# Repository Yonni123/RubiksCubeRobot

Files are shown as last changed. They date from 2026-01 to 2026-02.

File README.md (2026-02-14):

# Rubik's Cube Robot
<p align="center">
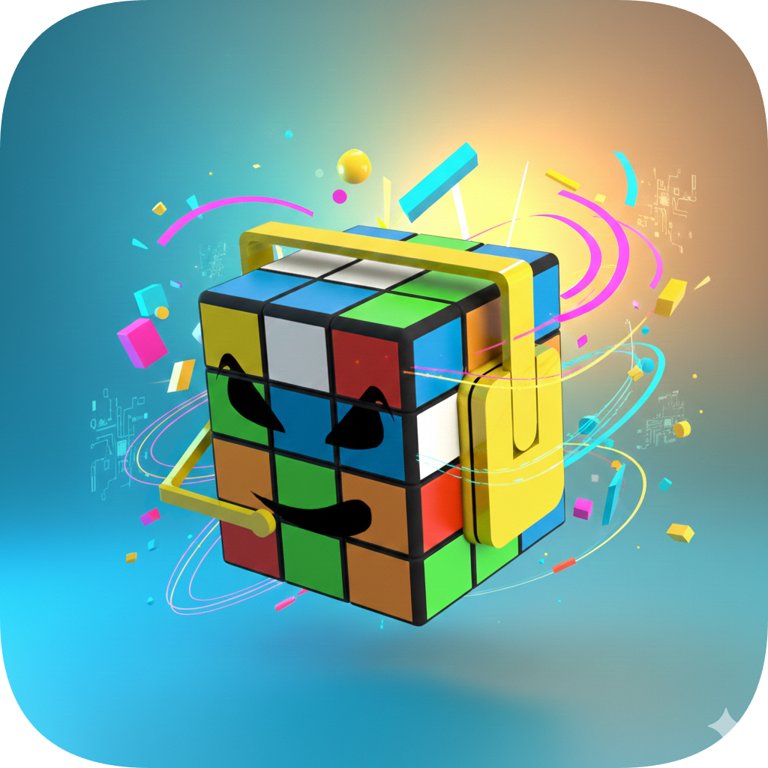
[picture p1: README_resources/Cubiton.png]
Pi-hole website
  
  <br>
</p>

An autonomous robotic system that can visually scan a scrambled Rubik's cube, compute the optimal solution, and solve it through precise servo-controlled manipulation.

## Video demo
<p align="center">
  <a href="https://www.youtube.com/watch?v=RQn-u8popRQ">
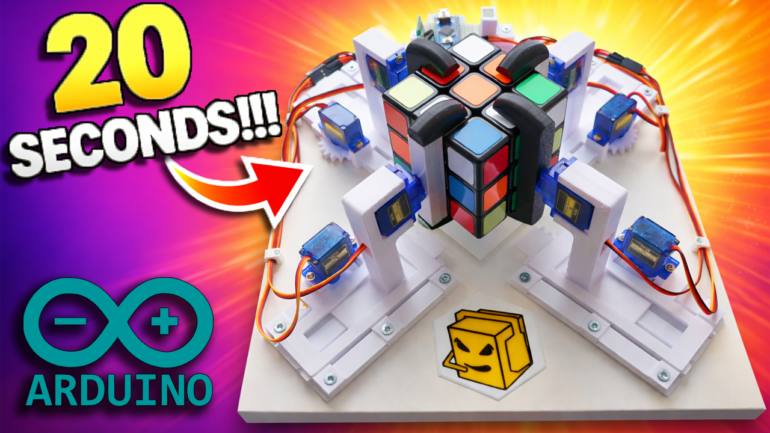
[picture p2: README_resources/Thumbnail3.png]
Project Demo Video
    
  </a>
</p>

## Project Overview

This project combines:
- **Hardware**: Arduino-controlled robotic actuators with 8 servo motors
- **Software**: Android mobile app for camera-based cube detection and Bluetooth control
- **Algorithms**: Kociemba two-phase algorithm for optimal cube solving

The system uses computer vision to analyze all 6 faces of a Rubik's cube, calculates the minimal solving sequence, and then executes it robotically.

## Getting started
Each folder in this repo is responsible for a different thing, with its own README.md that explains it further. I recommend doing them in the following order:
### Hardware
This is where you'll find hardware things that you will need, along with STL files ready for 3D printing and instructions for which parts to 3D print and how to assemble them. You'll also find Fusion 360 files of the same STL files in case you want to tweak them yourself. At the end, you should have the robot ready to be programmed.

### Arduino
When you've built the robot, it is time to flash the arduino with the firmware and configure it. This directory has a README that will show how this is done, and explain the API interface of the robot and how to talk with it.

### Cube Solver
Since the entire robot with the arduino is just sitting and waiting for commands, this Cube Solver is an android app that I developed as an example for how to control the robot. It combines computer vision with the phone's camera to scan the cube with Kociemba's algorithm to find the optimal solution for the cube, and streams the solution to the robot, which executes it. The README there shows how to install the app on an android phone and use it, but not much about the code itself, if you wanna improve it, be my guest :)

## Workflow: Solving a Cube

1. **User starts app** → Connects to Arduino via Bluetooth (HC-06)
2. **Scan Phase**:
   - Opens Scan tab
   - Robot rotates to expose each face
   - User taps "Scan Face" for each of 6 faces
   - App captures and processes images
3. **Processing**:
   - Converts color detection to Kociemba format
   - Sends to two-phase solver (embedded `.jar`)
   - Returns optimal move sequence
4. **Solving**:
   - User sets speed
   - Taps "Solve"
   - App sends `MOVE` command with sequence
   - Arduino executes servo movements
   - Phone listens for IDLE/BUSY status updates
5. **Done**: Cube is solved, robot returns to rest position

## Known issues
The layout of the android application is different from device to device. Depending on resolution, it might be perfect or completely ruined and almost unusable.

## Future Improvements

- Make the scanning computer vision part better
- The SEQ command and the API in general takes up the entire RAM cuz I was lazy
- Actually implement the control tab
- When pressing Solve, Open or Close buttons, disable them immediately and wait for robot to respond (just like we do with scan buttons)

---

**Created**: January 2026  
**Author**: Yonan Yonan  
**License**: Do whatever the fuck you want license, as long as you don't sell any of this or profit from it in any way

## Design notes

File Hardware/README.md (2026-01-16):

# Hardware
In this folder, you'll find STL files, Fusion 360 files, electronics and much more..

## What you'll need (aside from 3D printing)
A wooden base. Minimum dimensions of 240x240mm. But, in my case, I needed it a little longer for my breadboard, so I had 240x270mm. Make sure the width is 240mm and the length is at least 240mm, but it can be as long as you need. The depth should ideally be between 20-30mm since we will be screwing and nailing things on this base. But my point is, the actuators themselves will take up space of 240x240mm in total.

Eight servo motors (SG90 or its metal equivalent that has the same dimensions). 

A breadboard with some jumper wires for circuitry.

Power adapter that is a steady 5 volts and at least 3 amps. Anything less will not work, but ideally, I would recommend more amps.

An arduino, any arduino here will work, but I went with Arduino Nano since it is small and fits nicely on the breadboard.

A breadboard or a PCB, whatever you want to connect the wires and circuitry really..

HC-06 or HC-05 bluetooth module for communication between the phone and the robot.. oh, and, an android phone.

3mm wooden screws that are 15mm long (to screw things into the wooden frame) and extra small screws (the same type that comes with the servo).

## Screw holes
I have made something I called "drill_jig.stl" cuz idk what else to call it. Anyway, it is a part that you can 3D print that will help you with drilling the screw holes in the right place. You just grab your 240x240mm wooden base (or draw a square of that size on it) and line it up with each of the 4 corners, and it will show you where the holes should be. You can mark them, drill and then throw that part away. You can also create a 2D version of it if you want and print it on paper.

## 3D printing, STL and Fusion 360
Let's look at how the final robot should look like:

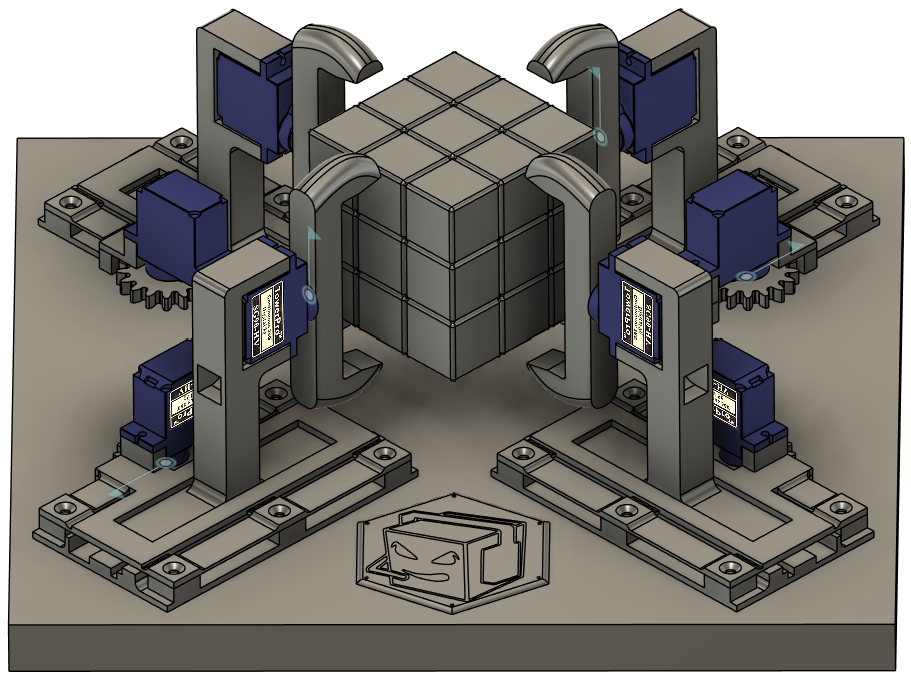
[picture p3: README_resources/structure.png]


To see a 3D version of that image, with clear parts, access this link: https://a360.co/49qhMGL

The password is: Cubiton

I do strongly suggest looking at it and using it as a manual for assembling the parts.

We can see four actuators. Two of them are normal and two of them are mirrored. (the definition of mirrored and normal is just my own). The upper-right in the image above and the bottom left actuators is what I defined as normal. The other two is what I defined as mirrored. Depending on where you want the gear and the servo to end up, you might want either all mirrored, all normal or like I did, two mirrored and two normal. If you want 3 mirroed or 3 normals you aren't normal :)

### Actuators
Each actuator is built up of 5 parts (aside from the two servos):
1. Grabber - the claw that grabs the rubiks cube. Mirroring doesn't matter for this one.
2. Slider - This is what holds the grabber and its servo, its the part that slides back and fourth.
3. Channel top - The part that holds the slider in the channel that it slides on. 
4. Channel bot - The channel itself that the slider should slide across. Since it can be rotated 180 degrees, mirroring shoudn't matter for this too.
5. Gear - This is what is mounted onto the bottom servo, that grabs the slider and pushes it back and fourth, also no mirroring. 

I hope this image makes the parts more clear:

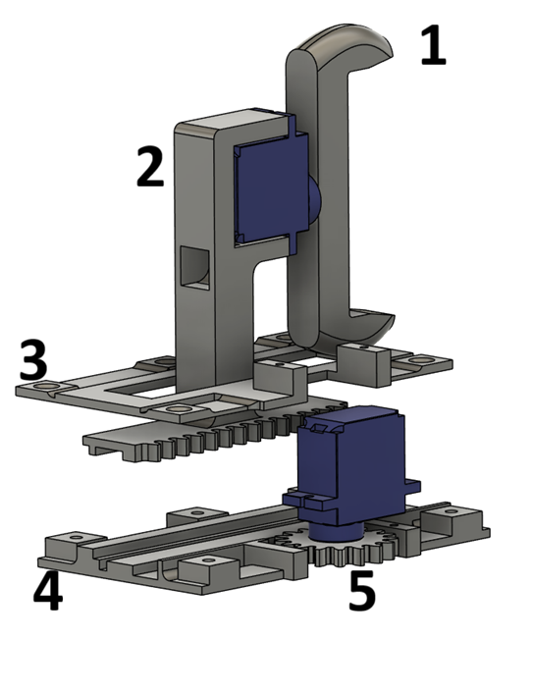
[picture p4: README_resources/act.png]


All of these parts make up one actuator, and we want four of them. First decide mirroring and what direction you want the gear servo to face. From now on, I will go on making two normals and two mirrored actuators.

#### Grabber
I have designed two types of grabbers, you can choose any one you like. One of them has a perfect fit in my servos, it might not fit your servo. The other grabber has a cut-out where a servo arm can be mounted onto it (the thing that comes with your servo). 
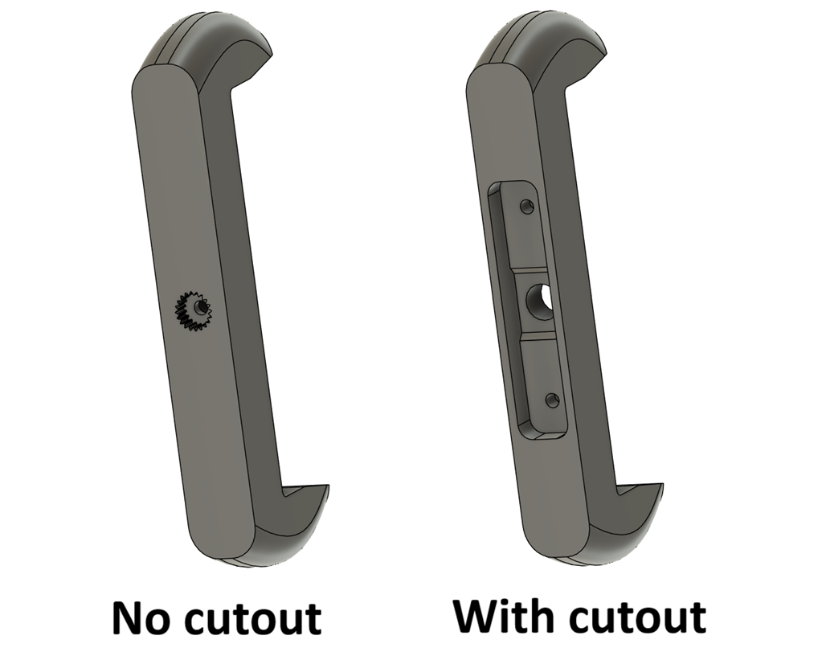
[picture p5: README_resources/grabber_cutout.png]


#### Gear
The gear has small cutout too, I don't recommend having a snap-on without anything holding it in place as this will move the entire slider back and fourth. What I did is have the servo arm with two little umm.. things? at the side.. I just snap off the long arms and only use the short arms because the gear is smaller. I hope this image will make it make sense :D
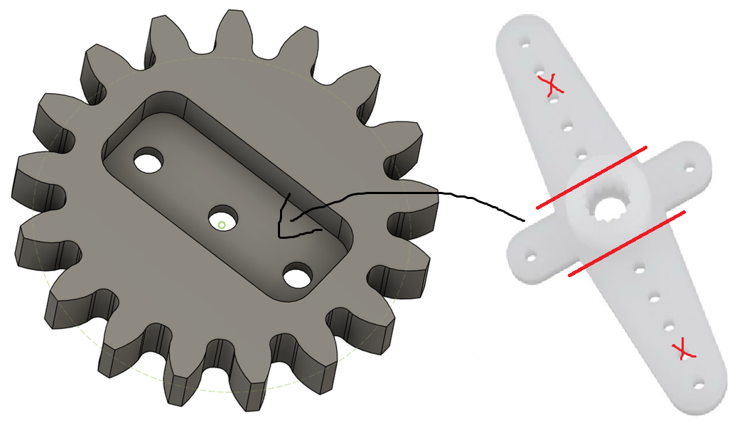
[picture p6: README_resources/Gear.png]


#### 3D printing
Before 3D printing anything, keep in mind that all the hole sizes and dimensions and cutouts fit my servos and my setup. Make sure:
- The cutout for the servo arms (or the grabber without the cutout) actually fits your servos and servo arms
- The grabber itself is a little bigger than the side of your cube (there must be a small 3-5mm gap between them, the cube should never get stuck inside the grabber)
- The screw holes themselves om the channel top and bottom, these will be screwed onto the wooden base
- The slider and the channel bottom, have a tolerance of 0.15mm, depending on your printer, you might wanna check that too otherwise it will not smoothly slide

I will make the Fusion 360 (where I designed them) files of these parts available in the Fusion 360 folder in this directory, you should be able to load them into Fusion and tweak them if you need to.

This is how I recommend you 3D print all parts (showing a single, normal actuator, the mirrored version should be printed in the exact same way)
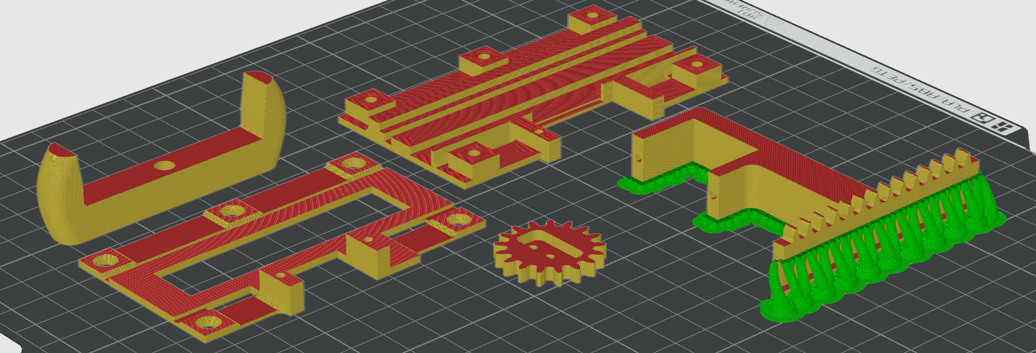
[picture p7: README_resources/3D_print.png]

The key takeaway is that, the gears on the slider needs to point up, only support the entire bottom face, and the two things that stick out at the bottom that will go into the channel later. Make it a manual tree support in Bambu Slicer. Also, make the channel bot (part numebr 4) has a top surface pattern set to concentric, so that the layer lines go along the channel, making the slider slide onto it smoothly.

When you have 3D printed these parts, you put them together like this:
But the bottom channel(4) on the wooden base. Put the slider(2) on it and make sure they slide smoothly (not too stiff or too wobbly). Put the top channel part(3) on top of them and screw them together onto the wooden base (5 screws in total).

Now, you can grab two servos, mount the gear on one servo and the grabber on the other (make sure the grabber is mounted in a way that lets it go between fully left, middle, and fully right). Slide the slider all the way in, rotate the gear manually so that it is also all the way in and mesh them together (to make sure the limit of the servo is literally the limit of how much you can push in the slider). Then just screw it in place. You should be able to slide the slider using the servo now, all the way in and however far back it goes (it goes back way too far we won't use all of it). Screw the grabber servo in place too and now you should have one actuator done. Repeat this 4 times.

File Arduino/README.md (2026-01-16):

# Arduino
Here you will first find how to wire things up in the arduino, and how to calibrate your servos with documentation of the overall arduino code and how it works. This is the slave part with the API that sits there and waits for commands.

## Circuit
You need an HC-06 or HC-05 bluetooth module for communication. When wiring up the servos, the PWM pin (orange wire usually) does not matter as long as you connected to one of the D2-D15 pins on the arduino (D0 and D1 are RX and TX, avoid those!). The TX and RX pins should be hooked up to the arduino's TX and RX using a voltage divider (since HC-06 logic works with 3.3v and not 5v). Below diagram shows how to wire up the HC-06 with a single servo (do the same with with the otehr 7 servos and just connect them to any diginal GPIO pins, it doens't matter which goes where.). The below diagram also assumes the power adapter provides a steady 5v with 3 amps or above. You can add capacitors to the motors too but I didn't bother.
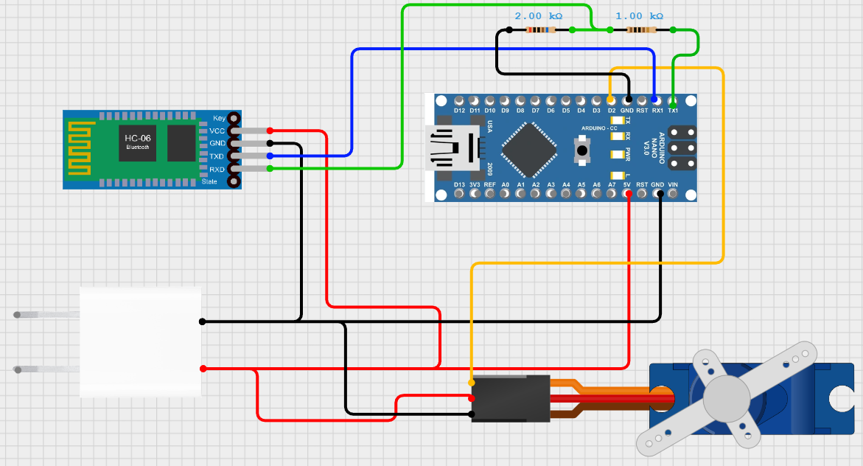
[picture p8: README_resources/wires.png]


### Actuator Definition
Which pin you connected each servo to does not matter, but the code expects this exact actuator definition (assuming the front of the robot is where my logo is):  
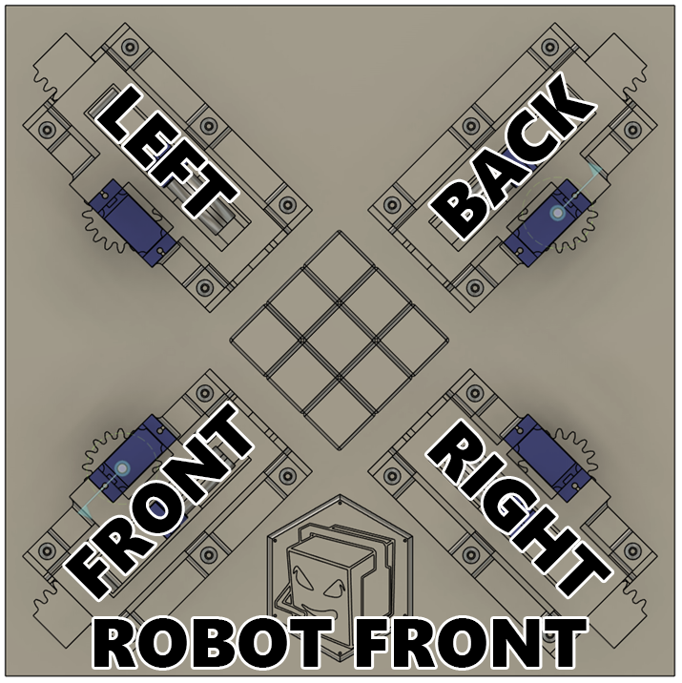
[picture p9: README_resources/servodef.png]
  
Each actuator will have a slider servo and a spinner servo. The slider is what makes it slide back and fourth, it is the servo with the gear. The spinner is the servo with the grabber that grabs the side of the rubiks cube and spins it. The pins you connected must be configured later based on this exact definition.

### Servo States
This application has a single servo class, with the exact same states, but they mean different things for spinners and sliders.

#### Spinner servo
Each spinner servo can move to 5 distinct positions:
- **STATE_C**: Center (fully centered)
- **STATE_L**: Left (fully left)
- **STATE_R**: Right (fully right)
- **STATE_l**: Center-left (45° between C and L)
- **STATE_r**: Center-right (45° between C and R)

#### Slider servo
- **STATE_C**: Center (Barely touching the rubik's cube without stalling)
- **STATE_L**: Left (Fully pressing into the rubik's cube, stalling)
- **STATE_R**: Right (Release, slide out, in this state, spinner can move freely and won't touch the cube)  
I guess sliders have a STATE_l and STATE_r as well since they use the same servo class, but here they do not make sense :) they just exist...

## Configuration (`Config.h`)
Before flashing your arduino with any of my code, I recommend using the servo sweep example code that comes with the arduino IDE to test all your sliders and spinners, to make sure all the wiring is correct. Then, open [Config.h](Config.h). In this file, you will find the definition for all the servo pins. You should change these to whatever digital pins you connected your servos to, depending on the actuator definition we talked about earlier. The other configuration is in case you want to run the program in calibration mode instead of normal mode (we will talk about it soon) and two buffers. One for SEQ command, which let's you control each servo individually, and MOVE command which let's you tell the robot actual rubik's cube moves. These buffer sizes worked for me so I do not recommend changing them unless you have a reason to. We will talk about these commands later.

## Calibration
> ### SERVO LIBRARY ISSUE
> **NOTE:** Before calibrating your servos, please be aware that my servo class is an abstraction on top of the standard `Servo.h` Arduino library. 
>
> **THE ISSUE:** You may find your servos have a "hard-limit" where they stop at 45° and 135° and refuse to go further. This is a known overflow bug within the official Servo library itself.
>
> **THE FIX:** You must manually patch the library. I found a community fix that resolves this overflow issue:
> * **Fix Link:** [GitHub Commit 7b4f264](https://github.com/arduino-libraries/Servo/pull/101/commits/7b4f26462c5053ac967b237c602000ad9ba54200)
>
>I highly recommend applying this change in your local library files; otherwise, it may be impossible to calibrate the servos correctly.  

Each servo is different, and STATE_C can mean different things for different servos. So, we must calibrate them once everything is working. Set the CALIBRATE flag to true in [Config.h](Config.h). However, try not to stay in this mode for too long as it keeps the servos constantly powered. Even if they aren't stalling, they are constantly micro-adjusting and will overheat if you leave it in this mode for a long time. This is mainly because I was too lazy, but meh, it needs to be done just a single time. After you set the CALIBRATE flag, remove the HC-06 bluetooth module and flash the arduino. Once it's done, open a serial monitor (BAUD 9600) and type H. It should show this message:
```
Servo calibration tool commands:
0-7 : select servo
c   : set state CENTER to calibrate center
l   : set state LEFT to calibrate left
r   : set state RIGHT to calibrate right
+/- : increase/decrease step size
*// : increase/decrease step size * 10
</> : increase/decrease center deviation (spinners only)
p   : Print current calibration values
w   : Write calibration to EEPROM
```  
First, select a servo to calibrate by writing a number between 0-7 in the serial monitor, it will show what you selected and current pulse and state after you press enter. After that, select state by sending r, l or c. (STATE_r and STATE_l cannot be selected here because their pulse will be calculated as the pulse between your STATE_R and STATE_C pulse). The idea here is that each state should be associated with a pulse for each servo. I recommend putting all sliders in C state, make them hold the cube in the middle, then put them in state R and clibrate it so that they are just out of reach of the cube, then state L that makes them press into the cube (to hold it up).  
Then, move onto the spinners, make sure the R and L are not a fully horizontal grabber, but a grabber that spins a little further than that. Because the grabber is a little bit bigger than the cube, to compenstate for that gap, it needs to spin a little more than 180 deg and a little less than 0 deg. The cheapest servos I bought was able to do it with enough calibration so there shouldn't be a problem :)  
However, going back to the center is a nightmare because it also needs that compensation. If the grabber only goes to the center, the side of the cube won't be fully at the center otherwise. So, I added something called center deviation (might be a wrong name, this is compensasion) that makes the grabber go a little bit to the left off the center, if it's coming from the right, and vice versa. But if it's in the center and it gets another center command, then it will not add compensasion. So, for true center, just send the center command twice.
When all these calibrations are done, you can press P to print them, or W to write them to the EEPROM so when you run it in normal mode, they will be read from there.

## **API Layer** (`API.cpp/h`)

Turn off the CALIBRATE flag and flash the arduino again (still without HC-06). In the serial monitor from the arduino IDE, you can type H again and this help message will be printed:
```
Commands:
HELP
PING
STATUS [servo]
SEQ <string>|C
MOVE <delay_ms> <orientation> <moves>
```
- `PING` - Connection test (should respond with PONG)  

Before explaining the rest of these commands, we should explain how we refer to each servo and state and cube orientation.
- Servo:   
   `R`, `L`, `F` or `B`: refers to RIGHT, LEFT, FRONT or BACK Slider servo  
   `r`, `l`, `f` or `b`: refers to RIGHT, LEFT, FRONT or BACK Spinner servo  
- State:  
   `R`, `r`, `C`, `l`, `L`: STATE_R, STATE_r, STATE_C, STATE_l, STATE_L  
   These work the exact same for spinners and sliders, but don't use r and l for sliders, again, they do not make sense  
Because of the mechanics of this robot, it can not access the UP and DOWN faces of the cube directly. It must flip the entire cube around.
When the cube is flipped, the UP and DOWN faces become the RIGHT and LEFT faces in the robot. The Right and Left faces on the cube are now pointing up and down and are inaccessible directly. In this orientation after the robot is flipped, the orientation is `INVERT` and the orientation is `1`. When the cube is NOT flipped and the UP and DOWN cube faces are inaccessible, it is `NORMAL` and orientation is `0`  

### STATUS command
- `STATUS [servo]` - Query robot state (IDLE/BUSY) or individual servo state (R, C or L)

### SEQ commnad
- `SEQ <string>|C` - Execute a predefined servo sequence or cancel.
If you just send `SEQ C`. It will cancel ANY operation it is currently doing and disable all servos. This is good for some kind of ABORT button. If it's already IDLE it will not do anything.  
If you send a sequence string instead, it is built like this:
`"<SERVO><STATE><SERVO><STATE>[OPTIONAL DELAY]"` and so on...
The sequence string will be executed from left to right IMMEDIATELY at the same time! unless it encounters a delay in the string, in which case it will wait and that amount of milliseconds before continuing the rest.
Example:
```
SEQ rRBL250fr  → Move right spinner to R, back slider to L, at the same time!, wait 250ms, front spinner to R
```  
You should plan your delay so that spinners aren't hitting each other, servos have enough time to move into position, but making the delays too large will cause the sequence to slow down, which is not ideal. You should just experiment with it. The perfect servo calibration can have delays as low as 120ms! but start with 250ms.

### MOVE command
- `MOVE <delay> <orientation> <moves>` - Execute standard Rubik's notation moves (U, D, L, R, F, B)
While you can use SEQ command to manually execute moves, it is exhausting to think in terms of SEQ instead of MOVES. It is also not possible as it stores the entire sequence stirng in RAM. A single move involve at least 4 servos, 6 if a cube flip is needed (U and B moves). A simple solution string will quickly blow up to a SEQ command over 2kb! This is why you should use the MOVE command to execute moves intead!  
You tell it how long it should wait for servos to get into position after commanding them, the start orientation of cube (how it is oriented right now, this is 0 for most of the time but set it to 1 when you need to) and following by the moves string defined as:  
R, L, F, B, U, D -> clockwise cube rotation of that face.  
r, l, f, b, u, d -> counter-clockwise cube rotation of that face.  
I know the standard move string is "FBF'U2" bla bla bla... but I wanted a simpler version where each character in the string mean a move! the equivalent of the move string I just said in my definition will be "FBfUU".  
Example:
```
MOVE 210 0 UfRF  
→ Cube orientation is NORMAL now (0), execute UP clockwise, so flip cube, then turn the face 90 degrees clockwise. 
→ Turn the FRONT face counter-clockwise
→ Turm the RIGHT face clockwise, but the orientation is INVERT now, we flipped it before, so flip it back and turn RIGHT face clockwise
→ Turn FRONT clockwise
```

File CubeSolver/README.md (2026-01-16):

# Cube Solver

This is the Android application component of the Rubik's Cube Robot project. It provides a mobile interface for scanning a scrambled Rubik's cube using the device's camera, computing the optimal solving sequence with Kociemba's two-phase algorithm, and sending the solution to the Arduino-controlled robot for execution.

## Disclaimer
I must say that 90% of this app is fully vibe-coded and AI generated. I focused fully on designing the robot mechanics, 3D printing, CAD and the Arduino C++ code. I did NOT want to focus on learning Kotlin or Android Studio with its Compose UI. For these reasons, I let the AI generate most of that code, which breaks every best-practices you can think of. I simply did not care as long as it was working, but this app is an example of how you should NOT use AI in your work :)  But, in this README, I will explain how to use the app rather than how the code works.

## Installation
There should be an APK file somewhere in the Release of this github repo, just install it on any android device that has a camera and Bluetooth.

## Usage

1. **Setup**:
   - Ensure the Arduino robot is powered on and Bluetooth module is active
   - Before launching the app, open bluetooth tab and connect to the robot from there. It should be paired

2. **Bluetooth Connection**:
   - Launch the app and press Connect button at the top, it will show you a list of paired devices, choose the robot

3. **Scanning the Cube**:
   - After connection, go to SCAN tab, and press start scanning.
   - The robot will show you each side it wants to see, and you should scan it from the front of the robot.
   - After scanning all 6 sides, it will go to the confirmation phase, make sure all colors are correctly detected
   - The confirmation phase is important since the AI did not do a good job at color detection from images and I'm too lazy to fix it

4. **Solving**:
   - When scanning is done, you can go back to Home tab and you should see a Cube State along with a Solution
   - If your calibrations were perfect, you should be able to set the speed to 100% and press solve (I was able to)
   - Robot should just execute moves the solution :) If anything goes wrong press the ABORT button.

## Troubleshooting
If you need to troubleshoot anything, don't do it in the android app as it can not do much. Remove the HC-06 module, connect the arduino to your computer and give it SEQ and MOVE commands from the Arduino IDE Serial Monitor.

## Development
For code improvements or modifications, refer to the source code in `app/src/main/`.

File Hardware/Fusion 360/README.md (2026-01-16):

Open Fusion 360. File -> open and choose Main+assembly.f3z
There is also a .stp file in case you want to open these in another CAD software.
It will import ALL parts and main assembly and you can play around with them however you want

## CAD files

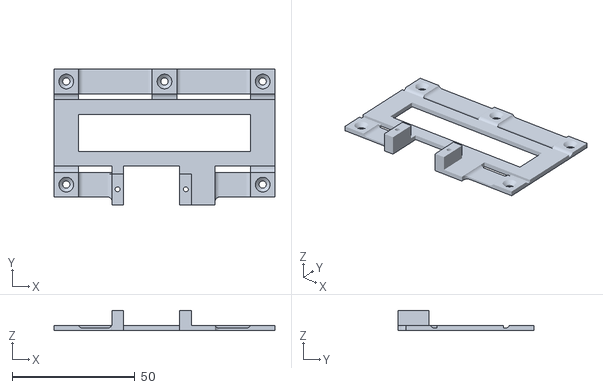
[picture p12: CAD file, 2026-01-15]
Hardware/STL/Channel top/ChannelTopNormal.stl
90.0 x 55.2 x 8.30

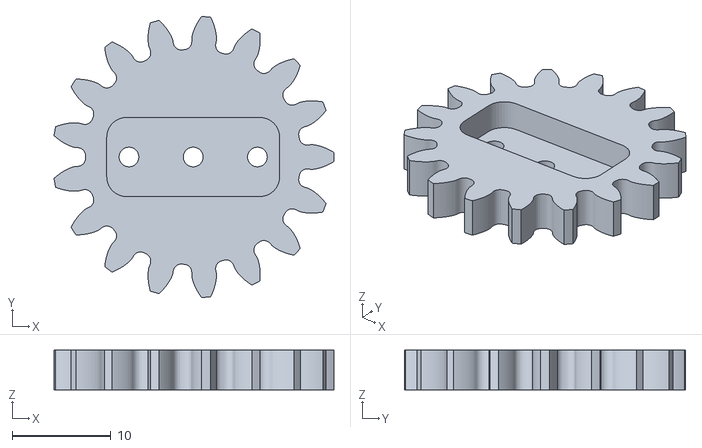
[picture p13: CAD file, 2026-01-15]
Hardware/STL/Gear.stl
28.3 x 28.4 x 4.00

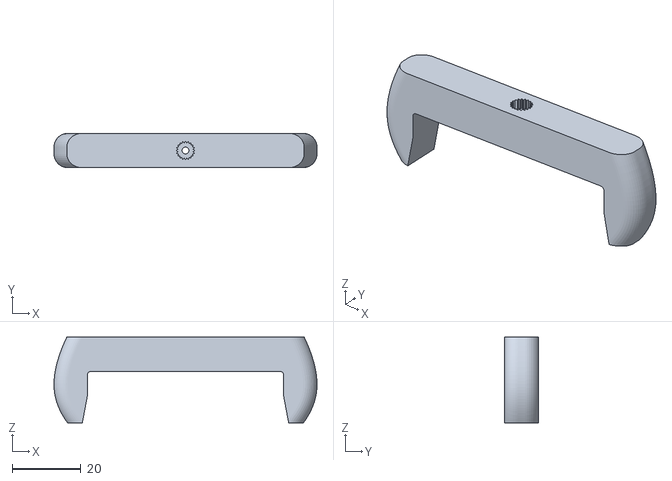
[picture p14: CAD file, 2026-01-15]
Hardware/STL/Grabber/Grabber - no cutout.stl
76.5 x 10.0 x 25.0

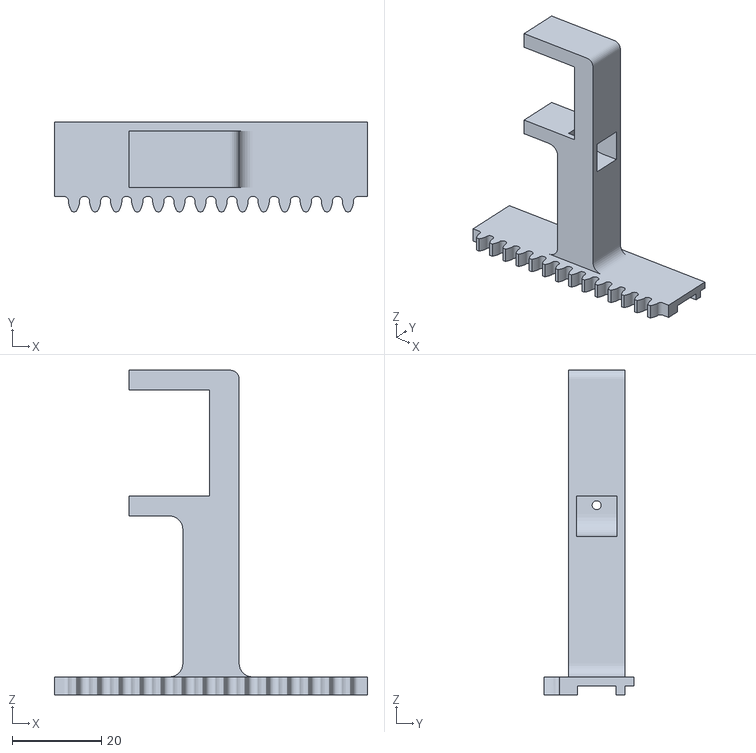
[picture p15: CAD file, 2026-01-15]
Hardware/STL/Slider/SliderNormal.stl
70.0 x 20.0 x 72.6

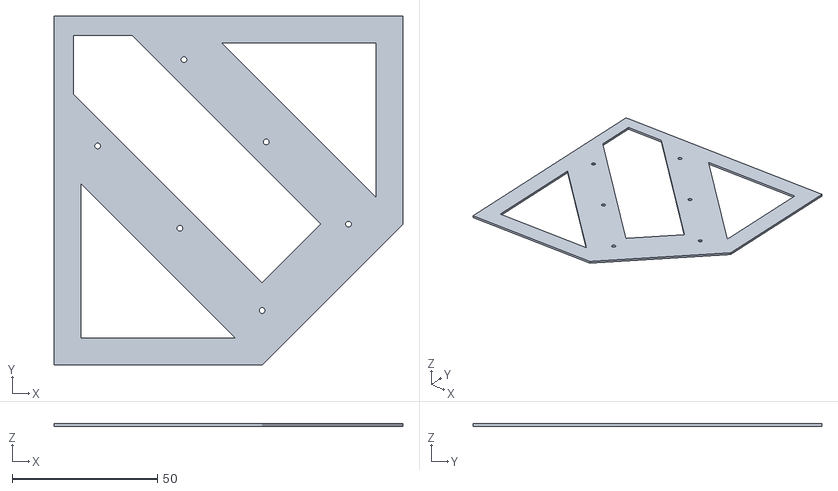
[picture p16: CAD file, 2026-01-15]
Hardware/STL/Drill_Jig.stl
120.0 x 120.0 x 1.00

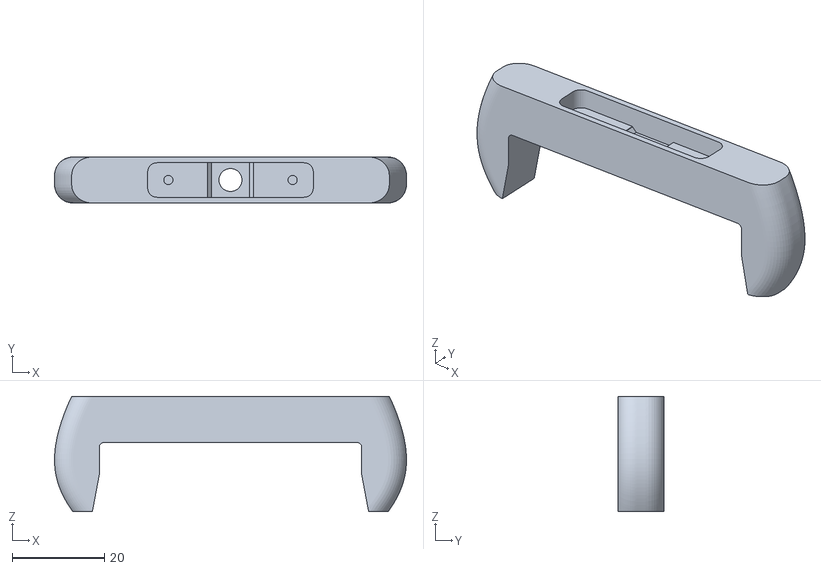
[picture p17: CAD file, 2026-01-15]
Hardware/STL/Grabber/Grabber - with cutout.stl
76.5 x 10.0 x 25.0

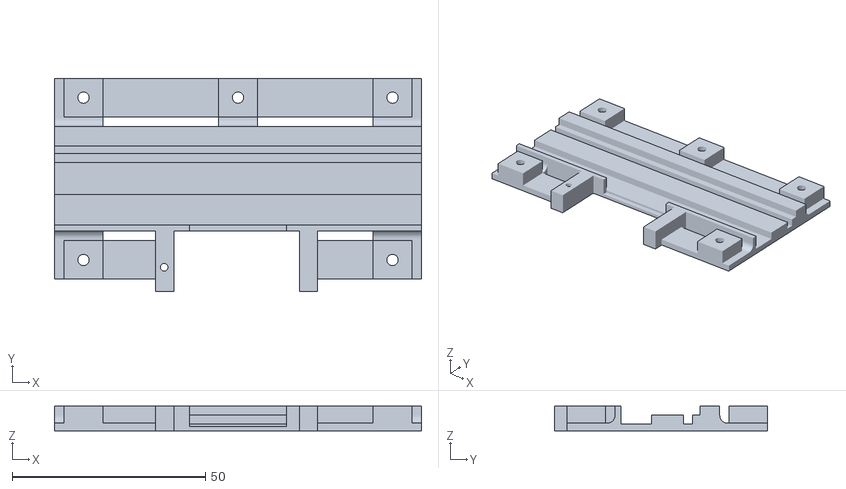
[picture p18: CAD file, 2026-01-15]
Hardware/STL/ChannelBot.stl
95.0 x 55.2 x 6.40

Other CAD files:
Hardware/STL/Channel top/ChannelTopMirror.stl
Hardware/STL/Slider/SliderMirror.stl

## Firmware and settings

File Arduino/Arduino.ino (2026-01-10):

#include "Calibrate.h"
#include "MyServo.h"
#include "SequenceManager.h"
#include "API.h"

void setup() {
    Serial.begin(9600);
    Serial.setTimeout(3000);
    calibrateSetup();   // Initialize EEPROM where calibrations are stored
#if !CALIBRATE
    APISetup();        // Setup API if not in calibration mode
#endif
}

void loop() {
    // During calibration, seqManager is never busy  
    if (millis() - seqManager.idleTimeMs < 3000 || seqManager.isBusy() || CALIBRATE)
        attachAllServos();
    else
        detachAllServos();
        
#if CALIBRATE
    calibrateLoop();
#else
    APILoop();  // Listen for API commands
    int res = seqManager.tick();    // If ongoing sequence, keep going
    if (res < 0)
    {
        Serial.print("SEQ ERR ");
        Serial.println(res);
    }
#endif
}

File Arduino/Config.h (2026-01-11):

// Set these to the Arduino pin numbers connected to each servo
// If you change these, it is recommended to recalibrate the servos
#define RIGHT_SLIDER_PIN 4
#define RIGHT_SPINNER_PIN 5
#define LEFT_SLIDER_PIN 17
#define LEFT_SPINNER_PIN 19
#define FRONT_SLIDER_PIN 16
#define FRONT_SPINNER_PIN 15
#define BACK_SLIDER_PIN 3
#define BACK_SPINNER_PIN 2

// If true, run the servo calibration tool instead of normal operation
// Set true only when you want to recalibrate servos
// After running in calibration mode, open serial monitor and type "h" for help
// It will let you control individual servos to calibrate them perfectly
#define CALIBRATE false

// Size of the buffer to hold active sequences in SequenceManager (SEQ command)
// A move (like U) can be a sequence like "rR220RR220rCrC220RC220rR2".
// Solving the cube, expect 24 moves to be safe, this quickly blows up to over 1kB ish.
// Please try not to exceed this size or increase it if your RAM allows it.
#define SEQUENCE_BUFFER_SIZE 256

// Size of the buffer to hold individual moves in MOVE command
// God's number is 20, but make it more to be safe.
// (Realistically, we will almost never find a perfect 20-move solution, unless its an easy scramble)
// But, based on real testing, 32 moves were exceeded, so make it larger.
#define MOVE_BUFFER_SIZE 64

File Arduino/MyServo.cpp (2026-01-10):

#include <Arduino.h>
#include <Servo.h>
#include "MyServo.h"
#include "Config.h"
#include "Calibrate.h"

#define MIN_PULSE_WIDTH 250
#define MAX_PULSE_WIDTH 3000

MyServo::MyServo(int pin, ServoType type, ServoCal calibration) :
    pin(pin),
    type(type),
    cal(calibration)
{
    if (static_cast<int>(type) % 2 == 0) {
        pulse = calibration.C_us;  // We want spinners default at center
    } else {
        pulse = calibration.R_us;  // We want sliders in release by default
    }
}

void MyServo::setState(ServoState next)
{
    switch (next)
    {
    case STATE_L:
        pulse = cal.L_us; break;
    case STATE_R:
        pulse = cal.R_us; break;
    case STATE_C:
        if (type % 2 == 1) // Slider
        {
            pulse = cal.C_us;
            break;
        }  
        if (state == STATE_L || state == STATE_l)
            pulse = cal.C_us + cal.CD_us;
        else if (state == STATE_R || state == STATE_r)
            pulse = cal.C_us - cal.CD_us;
        else
            pulse = cal.C_us;   // Double center is absolute center
        break;
    case STATE_r:
        pulse = (cal.C_us + cal.R_us) / 2; break;
    case STATE_l:
        pulse = (cal.C_us + cal.L_us) / 2; break;
    }
    state = next;
    thisServo.writeMicroseconds(pulse);
}

void MyServo::attach()
{
    if (!attached)
    {
        thisServo.attach(pin, MIN_PULSE_WIDTH, MAX_PULSE_WIDTH);
        thisServo.writeMicroseconds(pulse);
        attached = true;
    }
}

void MyServo::detach()
{
    if (attached)
    {
        thisServo.detach();
        attached = false;
    }
}

MyServo servos[NUM_SERVOS] =
{
    [RIGHT_SPINNER] = MyServo(RIGHT_SPINNER_PIN, RIGHT_SPINNER, readCalibration(RIGHT_SPINNER)),
    [RIGHT_SLIDER]  = MyServo(RIGHT_SLIDER_PIN,  RIGHT_SLIDER,  readCalibration(RIGHT_SLIDER)),
    [LEFT_SPINNER]  = MyServo(LEFT_SPINNER_PIN,  LEFT_SPINNER,  readCalibration(LEFT_SPINNER)),
    [LEFT_SLIDER]   = MyServo(LEFT_SLIDER_PIN,   LEFT_SLIDER,   readCalibration(LEFT_SLIDER)),
    [FRONT_SPINNER] = MyServo(FRONT_SPINNER_PIN, FRONT_SPINNER, readCalibration(FRONT_SPINNER)),
    [FRONT_SLIDER]  = MyServo(FRONT_SLIDER_PIN,  FRONT_SLIDER,  readCalibration(FRONT_SLIDER)),
    [BACK_SPINNER]  = MyServo(BACK_SPINNER_PIN,  BACK_SPINNER,  readCalibration(BACK_SPINNER)),
    [BACK_SLIDER]   = MyServo(BACK_SLIDER_PIN,   BACK_SLIDER,   readCalibration(BACK_SLIDER))
};

bool parseServoType(char c, ServoType& type)
{
    switch (c)
    {
        case 'R': type = RIGHT_SLIDER; return true;
        case 'L': type = LEFT_SLIDER; return true;
        case 'F': type = FRONT_SLIDER; return true;
        case 'B': type = BACK_SLIDER; return true;
        case 'r': type = RIGHT_SPINNER; return true;
        case 'l': type = LEFT_SPINNER; return true;
        case 'f': type = FRONT_SPINNER; return true;
        case 'b': type = BACK_SPINNER; return true;
        default: return false;
    }
}

void servoTypeToString(ServoType type, char* buffer, size_t bufferSize)
{
    switch (type)
    {
    case FRONT_SLIDER:
        strncpy(buffer, "FRONT_SLIDER", bufferSize); break;
    case FRONT_SPINNER:
        strncpy(buffer, "FRONT_SPINNER", bufferSize); break;
    case RIGHT_SLIDER:
        strncpy(buffer, "RIGHT_SLIDER", bufferSize); break;
    case RIGHT_SPINNER:
        strncpy(buffer, "RIGHT_SPINNER", bufferSize); break;
    case BACK_SLIDER:
        strncpy(buffer, "BACK_SLIDER", bufferSize); break;
    case BACK_SPINNER:
        strncpy(buffer, "BACK_SPINNER", bufferSize); break;
    case LEFT_SLIDER:
        strncpy(buffer, "LEFT_SLIDER", bufferSize); break;
    case LEFT_SPINNER:
        strncpy(buffer, "LEFT_SPINNER", bufferSize); break;
    default:
        strncpy(buffer, "UNKNOWN", bufferSize); break;
    }
}

void attachAllServos()
{
    for (int i = 0; i < NUM_SERVOS; i++)
    {
        servos[i].attach();
    }
}

void detachAllServos()
{
    for (int i = 0; i < NUM_SERVOS; i++)
    {
        servos[i].detach();
    }
}

// ====================
// Calibration adjustment
// ====================

void MyServo::adjustCalibration(int delta)
{
    if (state == STATE_C)
    {
        cal.C_us += delta;
    }
    else if (state == STATE_L)
    {
        cal.L_us += delta;
    }
    else if (state == STATE_R)
    {
        cal.R_us += delta;
    }
    pulse += delta;
    thisServo.writeMicroseconds(pulse);
}

void MyServo::adjustDeviation(int delta)
{
    if (type % 2 == 0) // Spinner
    {
        // Check if CD was subtracted or added previously
        if (pulse < cal.C_us)
        {
            cal.CD_us -= delta;
            if (cal.CD_us < 0)
                cal.CD_us = 0;
            pulse = cal.C_us - cal.CD_us;
        }
        else if (pulse > cal.C_us)
        {
            cal.CD_us += delta;
            pulse = cal.C_us + cal.CD_us;
        }
        thisServo.writeMicroseconds(pulse);
    }
}

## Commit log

2025-12-27 Calibration
    Add calibration code and calibrated motors with their Servo class
2025-12-28 Add cube controller
    We can now interpret cube moves instead of individual servos
2025-12-30 Move calibration to EEPROM and code refactor
    Fix better interfaces, better Servo class and types
    Made it more flexible to change the PIN number of servos
    Instead of copy-pasting calibration values, they are now
    read and written from and to the EEPROM
    [Arduino.ino, Config.h, calibrate.cpp]
2026-01-02 Change interface
    Removed old interface, now a caller has full control over servos
2026-01-03 Open/Close buttons work
2026-01-03 Add camera
2026-01-04 Change robot API
    Refrencing servos by numbers is confusing, change it to RLFBrlfb
    As for servo states, I added r and l, which is an intermediate
    position between R-C and C-L. This leaves a cube face at 45 deg
2026-01-05 Add new states, disable servos
2026-01-05 Add cube scanner, change API
    API now supports simultanious moves.
    Probably spelled that wrong idc
    [API.cpp, Arduino.ino, Config.h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]
2026-01-07 Add servo relax
    If robot hasn't been busy for the last second, disable the servos
2026-01-08 Switch to servo lib
2026-01-08 Switch cube rotation strategy
    Before it was rotate cube then grab.
    Now we rotate grabbers first, then center them to rotate cube
    It feels more stable this way
2026-01-10 Bugs and fixes
    Fix issue with deviation
    Fix issue with start orientation during moves
    Recalibration
    [API.cpp, Arduino.ino, MyServo.cpp]
2026-01-15 add STL files
    [ChannelBot.stl, ChannelTopMirror.stl, ChannelTopNormal.stl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]
